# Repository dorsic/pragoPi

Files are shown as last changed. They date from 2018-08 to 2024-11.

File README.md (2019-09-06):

# pragoPi
Pragotron watch driver with Raspberry Pi

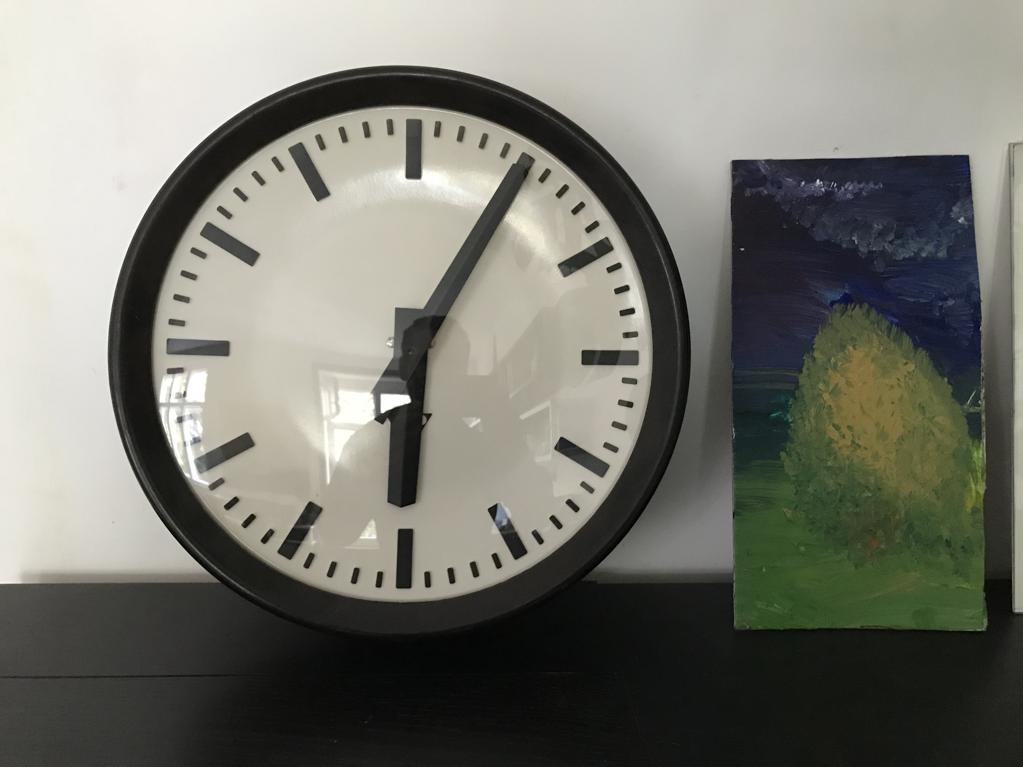
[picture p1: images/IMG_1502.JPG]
PJ 27


### Description
Pragotron slave watches were used in offices, schools, train stations all around Czechoslovakia and the states behind Iron Curtain. Model PJ 27 (on the picture above) from the 60s is made from bakelite but newer steel model from 80s can be found also on [eBay](https://www.ebay.co.uk/sch/i.html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). The Pragotron clock is moved by a magnetic coil feed with alternating impulses. Based on the watch these impulses can be between +-24V to +-60V. Each minute an impulse of length between 1000-2000 ms is generated by the master clock with opposite polarity than the previous one. This impulse applied on the coil in the movement moves the watch one minute forward.

To simulate the master clock a Raspberry Pi (RPi) is used with time synchronized by ntpd. A cron like scheduler issues an impulse on the beginning of each minute on pin 23 and 24. The L298 motor driver is used to allow altering higher voltage impulses polarization. Output of the module is connected to the clock terminals.

A simple web interface implemented using python Flask is used to set up the current time when needed and Linux service is created to start the application automatically after boot.

L298 IO drives some small silent current also when control signals from RPi pins 23 and 24 are low. 2000ms impulse length is just a fraction of entire minute, so we can keep the module off for majority of time (58s out of 60s) with usage of the switching transistor.

I prefer to use the Raspberry Pi Zero W because of its small factor, WiFi and price, but you can also use RPi2B or RPi3, which do not require soldering.

## Used Parts
- Pragotron slave watch
- Raspberry Pi Zero W
- L298 motor driver
- DC-DC voltage upscaler
- optionally one general purpose transistor (e.g. 2N2222) and 1k Ohm resistor
- Raspberry Pi power adapter
- Raspberry Pi power cable
- 4GB Class 10 microSDHC card or bigger

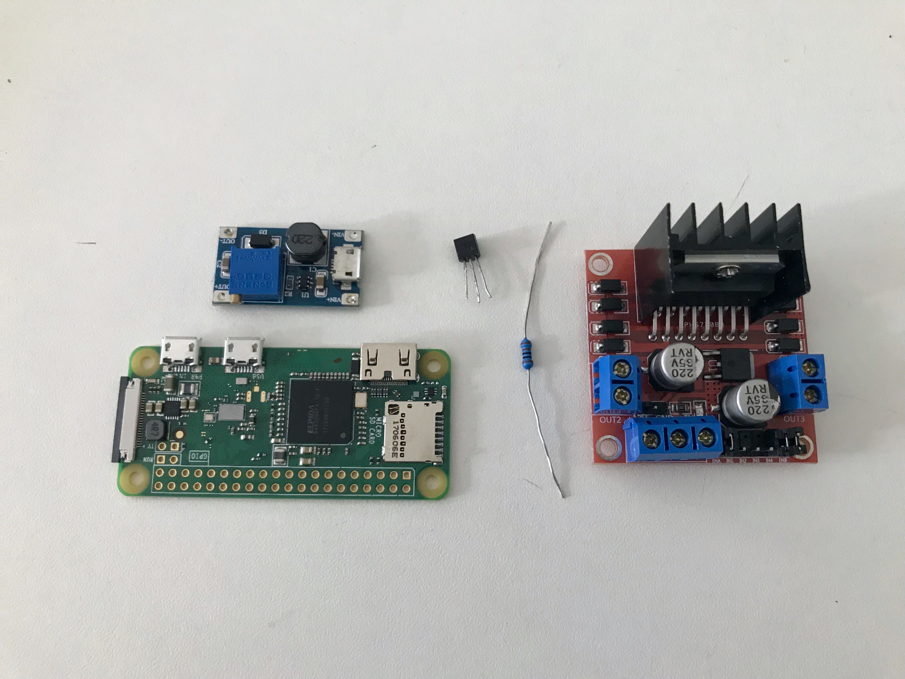
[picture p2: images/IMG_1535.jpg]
Used Parts


## Raspberry Pi Preparation
*(A brief description, for detailed instructions follow [Setting up your Raspberry Pi](https://projects.raspberrypi.org/en/projects/raspberry-pi-setting-up). If you have no keyboard and monitor like me, search for RPi headless installation.)*

Flash the operating system to SD card with Etcher. In my case I used the Raspbian Stretch Lite from 06-27-2018.
For headless setup without monitor and keyboard copy an empty file named `ssh` to the \boot partition of the SD card and `wpasupplicant.config` file with you WiFi configuration to allow your Raspberry Pi to connect to your network and log in via ssh.

Insert the SD card to RPi and boot.

Find out the RPi IP address. Use `netscan` or check your router or any other method to find out.
Consider to fix the IP address of you RPi on the router using a static IP settings.

Log in to you Rasbperry Pi via ssh. The default Raspbian password for *pi* user is *raspberry*.

```ssh pi@<RPI IP address>```

### Prepare the Raspberry Pi Operating System
*(Condensed version of [Finishing the setup](https://projects.raspberrypi.org/en/projects/raspberry-pi-setting-up/6).)*

Once logged in to you RPi I recommend to do some basic setup with `raspi-config`.
Issue 
```sudo raspi-config```
command and change the password and hostname (e.g. *pragoPi* as in my case) and set the country and time zone.

Next update you system with
```
sudo apt-get update
sudo apt-get upgrade
sudo apt-get dist-upgrade
```

##### Install NTPD
*(An optional but highly recommended step.)*

Using Network Time Protocol (NTP) is an easy way how to keep time on your RPi accurate. NTP servers are connected to GNSS or other accurate time sources (even primary time and frequency standards) and broadcast the time information to clients. NTP daemon witch runs in your RPi listens to this messages, computes the network delay, jitter and the corrections of frequency of the RPi oscillator to provide more accurate time information.

To install NTP daemon run following command
```
sudo apt-get install ntp
```
After a while, you can check with `ntpq -c pe` command if time servers where found. 
A server with an asterisk `*` is the primary server to which is the time of your RPi synchronized.
This is how the output may look like
```
     remote           refid      st t when poll reach   delay   offset  jitter
==============================================================================
 0.debian.pool.n .POOL.          16 p    -   64    0    0.000    0.000   0.002
 1.debian.pool.n .POOL.          16 p    -   64    0    0.000    0.000   0.002
 2.debian.pool.n .POOL.          16 p    -   64    0    0.000    0.000   0.002
 3.debian.pool.n .POOL.          16 p    -   64    0    0.000    0.000   0.002
+www.thr.sk      147.231.2.6      2 u  553 1024  377   15.036   -1.132  75.498
*cn10v1.christ-n 217.31.202.100   2 u  772 1024  377   15.148   -2.111   6.322
-95-105-193-228. 93.184.71.155    3 u  848 1024  377   19.133    6.851   3.832
+safi.initipi.sk 195.146.149.222  2 u  620 1024  377   26.503    1.262   7.782
-server.antechne 194.57.169.1     3 u  574 1024  377   15.989    0.608  13.697
+185.28.102.19 ( 124.216.164.14   2 u  691 1024  377   22.945    1.860   8.826
```

## Wiring

![Wiring Diagram](https://raw.githubusercontent.com/dorsic/pragoPi/master/images/wiring.png)

##### Connecting the DC-DC upscaler
Connect RPi PIN 4 (5V) to voltage upscaler input pin marked with sign (+) and the RPi PIN 6 (GND) to the upscaler input pin marked with sign (-).

##### Connecting the L298 motor driver
Remove the 12V jumper. Will supply 24V to our clock which is more than 12V. According to the module specification, we need to also supply separate 5V input voltage to the pin 6. 
Remove the motor 2 enable jumper (ENB) and leave in the motor 1 enable jumper (ENA) as we will use only the A output terminals.
Connect pin 4 of the motor driver to positive voltage output pin (OUT +) of DC-DC upscaler and pin 5 to the negative upcaler output pin (OUT -). 

If you are not using the switching general purpose transistor, then connect pin 6 to PIN 2 (5V) of your RPi to feed in logical voltage. Next wire pins 16 (GPIO23) and 18 (GPIO24) of your RPi to motor driver pins 8 (IN1) and 9 (IN2).

Connect the motor driver pins 1 and 2 (output terminals for motor A) to clock terminals.

Alternatively, if you want to use the switching general purpose transistor, then connect the RPi pin 2 (5V) to the anode of the transistor, the RPi pin 22 (GPIO25) to the transistor's base and the cathode of the transistor to pin 6 (5V) of the L298 motor driver.

## Install the App
We will install the application by downloading required python packages using pip and cloning the python source files from git repository.

#### Install Pip3
The app uses python3, so make sure you use the correct python version also for pip. To be on the safe side use pip and python commands with 3 at the end.
```
sudo apt-get install python3-pip
```

#### Install Required Modules (Python3)
- RPi-GPIO
```
sudo apt-get install python3-rpi.gpio
```

- APscheduler (3.5.1)
```
sudo pip3 install apscheduler
```

- Flask (1.0.2)
```
sudo pip3 install flask
```

#### Clone the repository
First install GIT if you have not done so before
```
sudo apt-get install git-core
```
and then clone the repository with command
```
cd ~
git clone https://github.com/dorsic/pragoPi
```
This will create a new directory pragoPi under your home directory and download the source files.

### Test the App
Now we are ready to test the app. To start the application run the `app.py` script.
```
cd ~/pragoPi
sudo python3 app.py
```
Flask web server will start to listen on port 80 for requests. If you issue the impulse request opening your web browser with URL `http://pragoPi:80/impulse` or  using `curl` command
```
curl -XGET http://pragoPi:80/impulse
````
your watch should progress one minute.

To set the time of the watch, you need to tell the app what time is the watch displaying. What is the position of the watch hands right now. To do this you can either edit the `clockStatus.conf` file and set the *displayedTime* property to the time shown by the clock, e.g. *11:19* or you can use the web API `setTime` request where you specify the time displayed by the clock as the URL parameter. You can use either 12- or 24-hour format, just leave out the separator (*:*) and leading zeros. Again the request can be sent via the web browser, just go to URL `http://pragoPi:80/setTime/2132` for example or using the `curl` command, e.g.
```
curl -XGET http://pragoPi:80/setTime/2132
```

Once again, that the parameter after the slash (*2132*) is the time displayed by your clock not current time. Since the RPi knows current time via NTP it advances the clock until the time displayed is in line with current time. 

Note, that all sample commands assume your RPi host name is pragoPi. If not, please alter the commands respectively.

##### Install System Service
In case of power outage and recovery we want the clock to automatically boot and set correct time. For this reason, current displayed time is stored to an permanent memory - file on the SD card and we create a Linux service, that will start the program upon boot.

To create the Linux service copy the `pragopi.service` service definition file to system services and set appropriate file access permissions.
```
sudo cp pragopi.service /lib/systemd/system 
sudo chmod 644 /lib/systemd/system/pragopi.service
chmod +x /home/pi/pragoPi/app.py
```

Now the services daemon can be reloaded to read the new service and we will enable and start the service. For this use these commands:

```
sudo systemctl daemon-reload
sudo systemctl enable pragopi.service
sudo systemctl start pragopi.service
```

### Web API
- Move clock one minute forward
`curl -XGET http://pragoPi:80/impulse`
- Set time
`curl -XGET http://pragoPi:80/setTime/<displayedTime>`
where *displayedTime* is the current time showed by the clock in HHMM format. Both 12- and 24- hour time formats are supported.

## Further extensions

The clockc is a 24/7 device so it is worth to pay attention to power consumption. You can apply some of the power saving techniques as:
- throttle down the cpu
- turn off unnecessary components and chips (e.g. usb and bluetooth)

Furthermore you can experiment with your own time source. You can extend the system with an RTC module or hook in a local PPS source derived from power line frequency to better overcome internet outages. Note that powerline frequency is quite a good time source and is managed to be alligned with UTC. You can check current status e.g. on [swiss grid](https://www.swissgrid.ch/en/home/operation/grid-data/current-data.html). 
But nowadays is wifi so common as the electricity and playing with 220V power lines requires knowledge and paying extra attention.

*If you think the project documentation needs enhancement in some chapters I would be happy to do so.*

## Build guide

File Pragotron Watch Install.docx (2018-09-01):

# 1. Requirements

Raspberry Pi Zero W

## Raspberry Pi Setup

- Rasbian Linux RPi 4.9.35+
- Python v3.5+
- Pip3
- Flask
- ntpd

Python modules

- RPi.GPIO
- Flask
- APscheduler

# 2. Installation

1. Copy the files to /home/pi/PragoPi
2. App.py and the templates directory with main.html should be copied
3. Create the system service to start the dashboard.
4. To test the aplication you can start it by

sudo python3 app.py

## PragoPi configuration

Several items can be configured in the application by editing the app.py file.

You can configure the

- application port (default 80)
- if __name__ == "__main__":
- scheduler = BackgroundScheduler()
- scheduler.add_job(doImpulse, trigger='cron', minute='*', id='minuter')
- scheduler.start()
- app.run(host='0.0.0.0', port=80, debug=False)

## Creating Raspberry Pi system services

The service for PragoPi needs to be created.

PragoPi is the main service providing the REST interface to query and control the time.

The service is started on Linux boot.

### PragoPi Service

1. Create file /lib/systemd/system/pragopi.service

With content

[Unit]

Decription=Pragotron Watch Service

After=multi-user.target

[Service]

Type=simple

ExecStart=/usr/bin/python3 /home/pi/PragoPi/app.py > /home/pi/PragoPi/pragopi.l$

Restart=on-abort

[Install]

WantedBy=multi-user.target

2. Set the file properties with commands

sudo chmod 644 /lib/systemd/system/pragopi.service

chmod +x /home/pi/pragoPi/app.py

sudo systemctl daemon-reload

sudo systemctl enable pragopi.service

sudo systemctl start pragopi.service

### How to check the service status

sudo systemctl status pragopi.service

### How to check the service logs

sudo journalctl -f -u pragopi.service

Background information on how to create a service is from

http://www.diegoacuna.me/how-to-run-a-script-as-a-service-in-raspberry-pi-raspbian-jessie/

# APPENDIX A – HOW TO RUN A SCRIPT AS A SERVICE IN RASPBERRY PI - RASPBIAN JESSIE

2 YEARS AGO (http://www.diegoacuna.me/how-to-run-a-script-as-a-service-in-raspberry-pi-raspbian-jessie/) • IOT (http://www.diegoacuna.me/category/iot/), LINUX (http://www.diegoacuna.me/category/linux/) • 8 (http://www.diegoacuna.me/how-to-run-a-script-as-a-service-in-raspberry-pi-raspbian-jessie/)

The Raspberry Pi (https://www.raspberrypi.org/) is an incredible popular credit card size mini computer with awesome capabilities. Despite of is mini size it behaves pretty much like a regular computer (it has an OS with a graphical interface, an ethernet port so you can surf the web, an HDMI output, etc.) but also it exposes several inputs/outputs (GPIO) to interact with the real world (sensors and cool tech gadgets).

A pretty common task when using this device, is to run some script (for example a python script) as a service in the operating system so it can start on boot, stop and restart using systemctl and more. In this post I'm going to explain how to set a little script as a service using Raspbian Jessie in a Raspberry Pi.

First of all, we are going to write a small python script which print "Hello World" every 60 seconds. This is going to be our service script (hello_world.py):

1 2 3 4 5 6 7 8 9 10 | #!/usr/bin/python from time import sleep try: while True: print "Hello World" sleep(60) except KeyboardInterrupt, e: logging.info("Stopping...")

You can execute it by python hello_world.py. If you get boring reading so many hello worlds, press Ctrl+C (or Cmd+C on OSX) to stop it. Save this file as hello_world.py in your home folder (home/pi/). Now we're going to define the service to run this script:

1 2 | cd /lib/systemd/system/ sudo nano hello.service

The service definition must be on the /lib/systemd/system folder. Our service is going to be called "hello.service":

1 2 3 4 5 6 7 8 9 10 11 | [Unit] Description=Hello World After=multi-user.target [Service] Type=simple ExecStart=/usr/bin/python /home/pi/hello_world.py Restart=on-abort [Install] WantedBy=multi-user.target

Here we are creating a very simple service that runs our hello_world script and if by any means is aborted is going to be restarted automatically. You can check more on service's options in the next wiki: https://wiki.archlinux.org/index.php/systemd.

Now that we have our service we need to activate it:

1 2 3 4 5 | sudo chmod 644 /lib/systemd/system/hello.service chmod +x /home/pi/hello_world.py sudo systemctl daemon-reload sudo systemctl enable hello.service sudo systemctl start hello.service

For every change that we do on the /lib/systemd/system folder we need to execute a daemon-reload (third line of previous code). If we want to check the status of our service, you can execute:

1 | sudo systemctl status hello.service

In general:

1 2 3 4 5 6 7 8 9 10 11 | # Check status sudo systemctl status hello.service # Start service sudo systemctl start hello.service # Stop service sudo systemctl stop hello.service # Check service's log sudo journalctl -f -u hello.service

REFERENCES

1. https://wiki.archlinux.org/index.php/systemd
2. https://www.digitalocean.com/community/tutorials/understanding-systemd-units-and-unit-files
3. https://coreos.com/os/docs/latest/getting-started-with-systemd.html

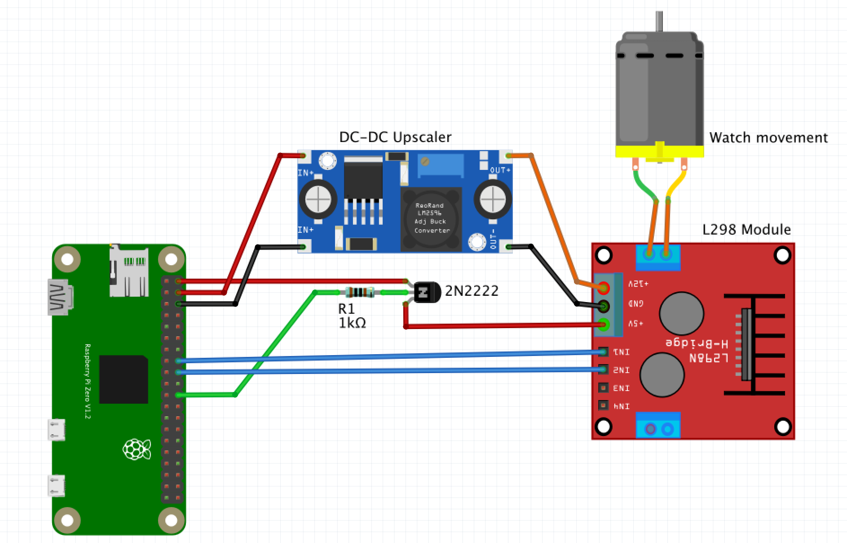
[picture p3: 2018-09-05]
images/wiring.png

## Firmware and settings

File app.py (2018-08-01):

'''
Controlling the Pragotron wall watch via pins 16, 18 (GPIO 23 and 24) using Cron Minute events.

'''
APP_VERSION = "0.2.0"

import os
import time
import datetime
import json
import RPi.GPIO as GPIO
from flask import Flask, render_template, request
from apscheduler.schedulers.background import BackgroundScheduler
import atexit

app = Flask(__name__)

def doImpulse():
    global clock
    clock.impulse(1.5)

class Pragotron(object):

    # Create a dictionary called pins to store the pin number, name, and pin state:
    pins = {
        23 : {'name' : 'GPIO 23', 'state' : GPIO.LOW },
        24 : {'name' : 'GPIO 24', 'state' : GPIO.LOW }
    }

    scheduler = BackgroundScheduler()

    lastImpulseStatus = { 'utctimestamp': None, 'impulseVoltage': 0, 'displayedTime': '' }
    statusFileName = None

    def __init__(self, statusFileName):
        self.statusFileName = statusFileName
        GPIO.setmode(GPIO.BCM)
        # Set each pin as an output and make it low:
        for pin in self.pins:
            print('Initializing pin ' + str(pin))
            GPIO.setup(pin, GPIO.OUT)
            GPIO.output(pin, GPIO.LOW)

        self.scheduler.add_job(doImpulse, trigger='cron', minute='*', id='minuter')
         
        if os.path.isfile(self.statusFileName):
            self.readStatus()
            self.setTime(self.lastImpulseStatus['displayedTime'])

        self.scheduler.start()

    def strToIntTime(self, timeStr):
        if ':' in timeStr:
            (h, m) = timeStr.split(':')
            return ((int(h)%12) * 100) + (int(m) % 60)
        if timeStr:
            return int(timeStr)

    def intTimeToStr(self, intTime):
        return "%02d" % (intTime//100,) + ':' + "%02d" % (intTime % 100,)

    def incTime(self):                
        intTime = self.strToIntTime(self.lastImpulseStatus['displayedTime'])
        if not intTime is None:
            intTime = intTime + 1
            intTime = intTime + 100-60 if intTime % 100 > 59 else intTime
            intTime = intTime - 1200 if intTime > 1159 else intTime
            self.lastImpulseStatus['displayedTime'] = self.intTimeToStr(intTime)

    def writeStatus(self):
        with open(self.statusFileName, 'w') as f:
            json.dump(self.lastImpulseStatus, f)

    def readStatus(self):
        with open(self.statusFileName, 'r') as f:
            self.lastImpulseStatus = json.load(f)

    def impulse(self, length = 1.5):
        print('Generating a ' + ('NEGATIVE' if self.lastImpulseStatus['impulseVoltage'] else 'POSITIVE') + ' impulse.')
        pin = list(self.pins.keys())[0] if self.lastImpulseStatus['impulseVoltage'] else list(self.pins.keys())[1]
        print('Setting pin ' + str(pin) + ' HIGH')
        self.pins[pin]['state'] = GPIO.HIGH
        GPIO.output(pin, GPIO.HIGH)
        time.sleep(length)
        self.pins[pin]['state'] = GPIO.LOW
        GPIO.output(pin, GPIO.LOW)
        self.lastImpulseStatus['utctimestamp'] = str(datetime.datetime.utcnow())
        self.lastImpulseStatus['impulseVoltage'] = (self.lastImpulseStatus['impulseVoltage'] + 1) % 2
        self.incTime()
        self.writeStatus()
        print('Impulse done.')

    def setTime(self, displayedTime):
        # disable schedule
        if not displayedTime:
            print("Unknown displayed time. Cannot set time.")
            return

        self.scheduler.pause_job('minuter')

        t = datetime.datetime.now()
        tnow = (t.hour%12) * 100 + t.minute
        cdt = self.strToIntTime(displayedTime)
        self.lastImpulseStatus['displayedTime'] = self.intTimeToStr(cdt)

        while cdt > tnow:
            print('Setting time, ' + str(cdt)  + ' > ' + str(tnow))
            self.impulse(0.3)
            time.sleep(0.3)            
            cdt = self.strToIntTime(self.lastImpulseStatus['displayedTime'])
            t = datetime.datetime.now()
            tnow = (t.hour%12) * 100 + t.minute

        while cdt < tnow:
            print('Setting time, ' + str(cdt) + ' < ' + str(tnow))
            self.impulse(0.3)
            time.sleep(0.3)            
            cdt = self.strToIntTime(self.lastImpulseStatus['displayedTime'])
            t = datetime.datetime.now()
            tnow = (t.hour%12) * 100 + t.minute

        print('Done in at ' + str(datetime.datetime.now()) + '. Resuming scheduler.')
        # enable scheduler
        self.scheduler.resume_job('minuter')

    def shutdown(self):
        self.scheduler.shutdown(wait=False)
        GPIO.cleanup()

def getTemplateData():
    global clock
    tnow = datetime.datetime.now()
    utcnow = datetime.datetime.utcnow()
    #tstr = tnow.isoformat(sep=' ', timespec='seconds')
    #utcstr = utcnow.isoformat(sep=' ', timespec='seconds')

    templateData = {
        'appVersion': APP_VERSION,
        'timestamp' : str(tnow),
        'utcTimestamp': str(utcnow),
        'lastImpulseStatus': clock.lastImpulseStatus,
    }
    return templateData


@app.route("/")
def main():
    templateData = getTemplateData()
    # Pass the template data into the template main.html and return it to the user
    return render_template('main.html', **templateData)
    
@app.route("/impulse")
def impulse():
    global clock
    clock.impulse(1.5)
    templateData = getTemplateData()
    return render_template('main.html', **templateData)    

@app.route("/setTime/<displayedTime>")
def setTime(displayedTime):
    global clock
    global scheduler
    clock.setTime(displayedTime)

    templateData = getTemplateData()
    return render_template('main.html', **templateData)

def cleanup():
    try:
        global clock
        clock.shutdown()
    except Exception:
        pass

atexit.register(cleanup)

if __name__ == "__main__":
    clock = Pragotron('/home/pi/pragoPi/clockStatus.conf')
    app.run(host='0.0.0.0', port=80, debug=False)

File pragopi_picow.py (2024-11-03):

import machine  
import time
import network
try:
  import usocket as socket
except:
  import socket

import ntptime

ssid = 'xxx'
password = 'xxx'

class PragoPi():
    led = machine.Pin('LED', machine.Pin.OUT)
    pwr_en = machine.Pin(15, machine.Pin.OUT)
    impl_pos_pin = machine.Pin(16, machine.Pin.OUT)
    impl_neg_pin = machine.Pin(17, machine.Pin.OUT)
    
    wlan = None
    ip = None
    tim = None	# minute timer
    dtim = None # day timer for ntp.settime
    wdt = None	# watchdog timer
    displayed_time = -1		# 0..719	720 = 12h * 60min
    min_len_s = 60 # ToDo: in production must be 60
    
    _last_imp = 0
    LONG_PULSE = 1.5
    SHORT_PULSE = 0.1 # 0

    def __init__(self):
        #self.wdt = machine.WDT(timeout=8000)  # 130 seconds
        #self.wtim = machine.Timer(period=6000, mode=machine.Timer.PERIODIC, callback=lambda t:self.wdt.feed())
        self.pwr_en.low()
        self.impl_pos_pin.low()
        self.impl_neg_pin.low()
        self.last_impulse = 0
        self.wlan = network.WLAN(network.STA_IF)
        self._jobid = 0
            
    def connect(self, ssid=ssid, password=password):
        print(f'connecting to {ssid}')
        self.wlan.active(True)
        self.wlan.connect(ssid, password)
        while self.wlan.isconnected() == False:
            n = 8
            for i in range(8):
                if self.wlan.isconnected():
                    break
                self.led.on()
                time.sleep(0.1)
                print('Waiting for connection...')
                self.led.off()
                time.sleep(0.9)
            if self.wlan.isconnected() == False:
                self.wlan.active(False)
                self.wlan.active(True)
                self.wlan.connect(ssid, password)
                print('Reconnecting self.wlan...')
        print(self.wlan.ifconfig())
        self.ip = self.wlan.ifconfig()[0]
        print(f'Connected on {self.ip}')
        print(f'local time: {time.localtime()}')
        self.displayed_time = self._to_display_time()
        return self.ip

    def _to_display_time(self, ts=None):
        t = ts if ts else time.localtime()
        #return (t[3]%12)*60 + t[4]
        dt = (t[3]%12)*3600 + t[4]*60 + t[5]
        dt = round(dt/self.min_len_s) * self.min_len_s
        return dt
    
    def _str_to_display_time(self, ts):
        s = ts.replace(':', '').strip()
        si = int(s)
        if len(s) > 4:
            return ((si//10000)%12) * 3600 + ((si//100)%100) * 60 + (si%100)
        return ((si//100)%12) * 3600 + (si%100) * 60

    def _display_time_to_str(self, dt):
        return f'{dt//3600:02}:{(dt//60)%60:02}:{dt%60:02}'
        
    def _time_to_str(self, ts=None):
        t = ts if ts else time.localtime()
        return f'{t[3]:02}:{t[4]:02}:{t[5]:02}'
            
    def _inc_display_time(self, dt):
        return (dt+self.min_len_s) % 43200
    
    def start_time(self):
        self.once_a_day()        
        self.dtim = machine.Timer(period=86400000, mode=machine.Timer.PERIODIC, callback=lambda t:self.once_a_day())
        
    def _of_minute_top(self):
        lt = time.localtime()
        wt = (lt[5]+1) % self.min_len_s
        return wt

    def start_minuter_job(self):
        if self.tim:
            self.tim.deinit()
            time.sleep(0.1)
                    
        wt = self._of_minute_top()
        if wt > 3:
            wt = self.min_len_s - wt + 1
            print(f'waiting for top of the second {wt} s')
            time.sleep(wt-1)
        self.tim = machine.Timer(period=self.min_len_s*1000, mode=machine.Timer.PERIODIC, callback=lambda t:self.once_a_minute(self._jobid))
        self._jobid += 1
        
    def stop_minuter_job(self):
        print(f'stopping job {self._jobid} ', end='')
        if self.tim:
            self.tim.deinit()
            time.sleep(0.1)
            self.tim = None
            self._jobid -= 1
            print('done')
        else:
            print(' no job')

    def start_server(self):
        # expects 
        s = socket.socket(socket.AF_INET, socket.SOCK_STREAM)
        s.bind(('', 80))
        s.listen(3)
        
        while True:
            try:
                conn, addr = s.accept()
                conn.settimeout(3.0)
                print(f'Received HTTP GET connection request from {addr}')
                request = conn.recv(1024)
                conn.settimeout(None)
                request = str(request)
                print(f'GET Request Content = {request}')
                
                tstart = request.find('/')+1
                tend=request.find('HTTP')
                new_disp_time = request[tstart:tend].strip()
                if new_disp_time:
                    try:
                        new_disp_time = self._str_to_display_time(new_disp_time)                        
                        print(f'New display time value: {new_disp_time}')
                        self.set_displayed_time(new_disp_time, start_job=True)
                        response='OK\n'
                    except:
                        response=f"Invalid value '{new_disp_time}', must be in format hh[:]mm[:][ss].\n"
                else:
                    response=f'{self.displayed_time} - {self._display_time_to_str(self.displayed_time)}\n'
                
                conn.send('HTTP/1.1 200 OK\n')
                conn.send('Content-Type: text/plain\n')
                conn.send('Connection: close\n\n')
                conn.sendall(response)
                conn.close()
            except OSError as e:
                conn.close()
                print('Connection closed')
    
    def set_displayed_time(self, displaying_time=None, start_job=True):
        # move clock hands to display_time
    
        # disable schedule
        self.stop_minuter_job()
        cdt = displaying_time if displaying_time else self.displayed_time
        if not cdt:
            print("Unknown display time. Cannot set time.")
            return

        tnow = self._to_display_time()
        while (cdt != tnow):
            self.progress_display_time(self.SHORT_PULSE)
            cdt = self._inc_display_time(cdt)
            tnow = self._to_display_time()
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

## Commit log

2018-08-01 Corrected file paths in code
    [app.py]
2024-11-03 Create pragopi_picow.py
    RPi Pico W version of the controller. No need for RPi Zero W. Faster boot, easer to manage.
